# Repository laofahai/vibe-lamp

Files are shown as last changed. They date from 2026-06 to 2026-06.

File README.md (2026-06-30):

**English** | [简体中文](README.zh-CN.md)

# Vibe Lamp

Physical ambient status light for AI coding agents.

Vibe Lamp turns local coding-agent state into desk light: blue when the agent is working, green when it finishes, red when it needs you, and amber when the connection is lost.

<p align="center">
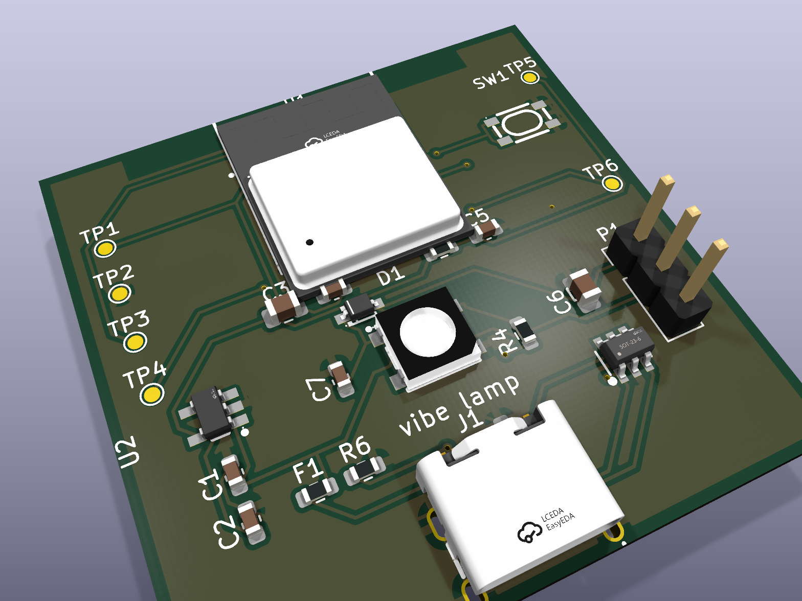
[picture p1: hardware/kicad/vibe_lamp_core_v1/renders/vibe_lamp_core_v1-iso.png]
Vibe Lamp Core V1 PCB 3D render
  
</p>

Core V1 is a complete ESP32-C3 controller board with USB-C power/programming, a board-mounted WS2812B status LED, a reset/provisioning button, and a reserved WS2812 expansion pad. The KiCad source, 3D renders, Gerber, BOM, and CPL files are included.

Inspired by [Vibe Island](https://vibeisland.app/), but independent from it. Vibe Lamp consumes agent hooks directly and can coexist with other hook consumers.

---

## Agent Support

| Level | Agents / tools | How it works |
|---|---|---|
| Built in | Claude Code, Codex | `daemon/install.py` installs local hooks and launchd autostart on macOS. |
| Generic API | OpenCode, Qwen Code, Gemini CLI, Aider, Cursor, Windsurf, CodeBuddy / WorkBuddy, Trae, MarsCode / Doubao, Factory / Droid-style tools | Any tool that can run a hook, plugin, wrapper, or notification command can POST normalized events to `/event/generic`. |
| Future adapters | Tool-specific integrations | Add adapter logic in the Mac daemon only; the ESP32 firmware stays agent-agnostic. |

Generic event example:

```bash
curl -s -o /dev/null --max-time 1 \
  -X POST http://127.0.0.1:8787/event/generic \
  -H 'Content-Type: application/json' \
  -d '{"agent":"opencode","session_id":"default","state":"working","tool":"code"}' || true
```

Supported normalized states are `idle`, `working`, `done`, `error`, and `needs_you`. See [daemon/AGENTS.md](daemon/AGENTS.md) for adapter notes.

---

## Architecture

All decision-making lives on the Mac. The ESP32 is a display endpoint.

```
Claude Code / Codex / generic agent
        │
        ▼
Mac daemon
  - normalizes hook events
  - merges multiple sessions
  - pushes state + heartbeat
        │ WiFi / HTTP
        ▼
ESP32 firmware
  - renders LED color/animation
  - enters lost state when heartbeat stops
```

Merge priority for a single LED:

```text
needs_you > error > working > done > idle
```

The lamp never freezes on stale state: if the daemon or network disappears, firmware switches to amber lost mode after the watchdog timeout.

---

## Hardware

Two hardware paths are supported:

| Path | Use it for | Notes |
|---|---|---|
| Core V1 PCBA | Finished build | Recommended. Factory-assembled ESP32-C3 board with board-mounted WS2812B. |
| Breadboard prototype | Bring-up and experiments | ESP32 dev board plus RGB LED or WS2812 ring. |

<p align="center">
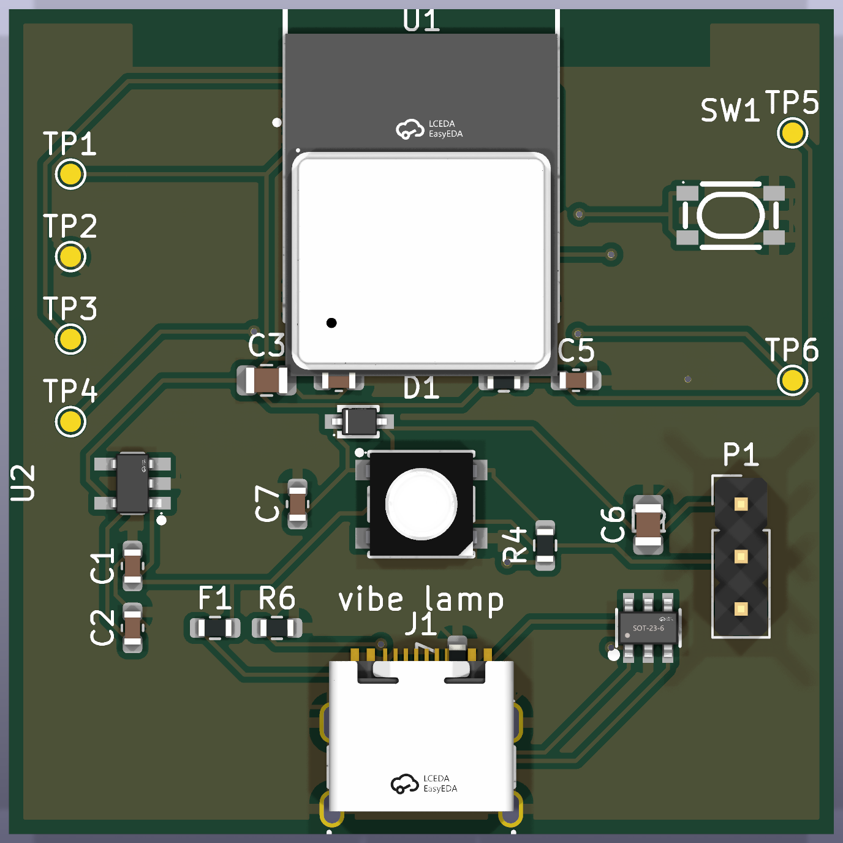
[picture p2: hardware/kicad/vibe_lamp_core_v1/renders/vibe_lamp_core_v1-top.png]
Vibe Lamp Core V1 PCB top render
  
</p>

Core V1 production files live in [hardware/kicad/vibe_lamp_core_v1](hardware/kicad/vibe_lamp_core_v1):

- KiCad PCB source
- PCB renders
- JLCPCB Gerber zip
- JLCPCB BOM and CPL

<details>
<summary>Breadboard prototype parts</summary>

RGB LED prototype:

| Part | Qty | Notes |
|---|---:|---|
| ESP32 dev board | 1 | Any `esp32dev`-compatible board |
| Common-cathode RGB LED | 1 | 4-pin LED |
| 220 ohm resistor | 3 | One per R/G/B channel |
| Breadboard | 1 | Bring-up |
| Jumper wires | Several | Board-dependent |
| USB data cable | 1 | Power and flashing |

WS2812 ring prototype:

| Part | Qty | Notes |
|---|---:|---|
| ESP32 dev board | 1 | Same firmware stack |
| WS2812 / WS2812B ring | 1 | 16 LEDs by default |
| 330 ohm resistor | 1 | In series with DIN |
| 1000 uF electrolytic capacitor | 1 | Across 5V and GND |
| Jumper wires + USB data cable | Several | Power, data, flashing |

</details>

Detailed wiring, flashing, WiFi provisioning, and self-test steps are in [HARDWARE.md](HARDWARE.md).

---

## Quick Start

```bash
# Core V1 firmware
cd firmware
pio run -e c3_core_v1 -t upload

# Mac daemon + Claude Code / Codex hooks
cd ../daemon
python install.py install
```

After WiFi provisioning, test the lamp directly:

```bash
curl --noproxy '*' -X POST http://vibelamp-<id>.local/state \
  -H 'Content-Type: application/json' \
  -d '{"sessions":[{"state":"working","tool":"code"}]}'
```

---

## Development

```bash
# Daemon tests
cd daemon
python -m pytest

# Firmware logic tests
cd ../firmware
pio test -e native

# Firmware builds
pio run -e c3_core_v1
pio run -e esp32
pio run -e esp32_ring
```

The `pio` command can use the repo virtualenv: `.venv/bin/pio`.

---

## Status

Done:

- ESP32 firmware: WiFi provisioning, HTTP state API, mDNS, watchdog lost mode, RGB/WS2812 display drivers, animations, multi-session rendering.
- macOS daemon: Claude Code and Codex hooks, generic event API, session merge, heartbeat, retry, rediscovery, launchd autostart.
- Core V1 hardware: KiCad board source, renders, JLCPCB Gerber/BOM/CPL.

Planned:

- Dedicated adapters for more coding agents.
- OTA firmware update.
- Phone control page.
- Enclosure and diffuser polish.
- BLE fallback when WiFi is unavailable.

---

## Repository Layout

```text
vibe-lamp/
├── hardware/    # Core V1 docs, KiCad source, renders, fab outputs
├── firmware/    # ESP32 firmware, PlatformIO environments, native tests
├── daemon/      # macOS daemon, hook installer, normalization logic, pytest
└── scripts/     # release packaging helpers
```

---

## License

MIT. See [LICENSE](LICENSE).

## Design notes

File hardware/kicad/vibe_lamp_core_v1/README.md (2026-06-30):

# Vibe Lamp Core V1 (KiCad)

Core V1 桌面状态灯主控板的 KiCad 工程目录。当前版本已经包含 PCB 源文件、渲染图、JLCPCB Gerber/BOM/CPL 输出，可作为 PCBA 打样下单基础。

40×40mm 圆角方板 · 2 层 · ESP32-C3-MINI-1（自带 PCB 天线，天线 keep-out 在位）· USB-C 供电+原生 USB · 板载 3.3V LDO · 板载 WS2812B 状态灯 · WS2812 扩展焊盘 · 清网按钮 · 工厂贴片，用户不焊接主板。

## 当前状态

- 电气完整：0 短路、0 未连接。
- 生产资料已生成：`fab/vibe_lamp_core_v1-gerber.zip`、`fab/vibe_lamp_core_v1-bom.csv`、`fab/vibe_lamp_core_v1-cpl.csv`。
- 3D 预览图在 `renders/`。
- 详细布线/DRC 说明见 `../../v1_routing_status.md`。

## 目录内容

| 路径 | 用途 |
|---|---|
| `vibe_lamp_core_v1.kicad_pcb` | PCB 源文件 |
| `vibe_lamp_core_v1.kicad_pro` | KiCad 工程配置 |
| `libs/` | 本工程使用的符号、封装、3D 模型 |
| `scripts/` | 生成/布线/导出辅助脚本 |
| `renders/` | 顶视与等轴测 3D 渲染图 |
| `fab/` | JLCPCB 下单文件 |

## 下单入口

1. 先读 `../../v1_routing_status.md`，确认剩余 DRC 告警的性质。
2. JLCPCB 下单时上传 `fab/vibe_lamp_core_v1-gerber.zip`。
3. 选择 PCBA 后上传 `fab/vibe_lamp_core_v1-bom.csv` 与 `fab/vibe_lamp_core_v1-cpl.csv`。
4. 被动件按阻值/容值在 JLCPCB 页面确认基础库匹配。

## 注意
- 天线 keep-out 是本板第一约束：模组天线端贴板边，该区域两层禁铜/禁走线/禁过孔/禁器件。
- 下单/编辑前留意 KiCad 自动回写 `.kicad_pro` 的问题，详见 `../../v1_routing_status.md`。

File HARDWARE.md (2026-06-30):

# Vibe Lamp · 硬件上手指南

这是一份「从硬件到灯随会话变色」的分步清单。Core V1 PCBA 是推荐路径；面包板原型保留给快速验证和固件调试。

> 命令里的 `pio` / `python` 可直接用仓库自带虚拟环境：
> - `/Users/laofahai/Documents/workspace/vibe-lamp/.venv/bin/pio`
> - `/Users/laofahai/Documents/workspace/vibe-lamp/.venv/bin/python`
>
> 下文为简洁起见写成 `pio` / `python`，把它换成上面的绝对路径即可（或先 `source .venv/bin/activate`）。

---

## 0. 你需要什么

两条路任选其一往下走：

- **Core V1 PCBA（推荐）**：使用本仓库 KiCad 工程和 `fab/` 里的 JLCPCB 文件下单，收到的是工厂贴好的主控板。用户不需要焊接主板，只需要 USB-C 烧录、配网、装外壳。
- **面包板原型**：用 ESP32 开发板、RGB LED 或 WS2812 灯环快速验证固件和灯效。

Core V1 生产资料：

| 文件 | 用途 |
|---|---|
| `hardware/kicad/vibe_lamp_core_v1/vibe_lamp_core_v1.kicad_pcb` | KiCad PCB 源文件 |
| `hardware/kicad/vibe_lamp_core_v1/renders/` | PCB 3D 渲染图 |
| `hardware/kicad/vibe_lamp_core_v1/fab/vibe_lamp_core_v1-gerber.zip` | JLCPCB Gerber 上传包 |
| `hardware/kicad/vibe_lamp_core_v1/fab/vibe_lamp_core_v1-bom.csv` | JLCPCB 贴片 BOM |
| `hardware/kicad/vibe_lamp_core_v1/fab/vibe_lamp_core_v1-cpl.csv` | JLCPCB 贴片坐标 |
| `hardware/v1_routing_status.md` | 布线、DRC、下单注意事项 |

<p align="center">
  Vibe Lamp Core V1 PCB 3D render
</p>

### 物料清单 A — 打样版（单颗共阴 RGB LED）

| 物料 | 数量 | 备注 |
|---|---|---|
| ESP32 开发板 | 1 | 手上现成的即可（`esp32dev`） |
| 共阴 RGB LED（4 脚） | 1 | 一个公共**阴极** + R/G/B 三脚 |
| 限流电阻 ~220Ω | 3 | R/G/B 各一颗 |
| 面包板 | 1 | |
| 杜邦线 | 若干 | |
| USB 数据线 | 1 | 烧录 + 供电 |

### 物料清单 B — 进阶版（WS2812 灯环）

| 物料 | 数量 | 备注 |
|---|---|---|
| ESP32 开发板 | 1 | |
| WS2812 / WS2812B 灯环（16 灯） | 1 | 可寻址，支持多会话分段 |
| 限流电阻 ~330Ω | 1 | 串在数据线 DIN 上 |
| 电解电容 ~1000µF | 1 | 并在 5V 与 GND 之间，护电源 |
| 杜邦线 | 若干 | |
| USB 数据线 | 1 | |

> 引脚以固件 `firmware/include/config.h` 的实际值为准（下面接线表已对齐）。换板/换脚改 config.h 即可，不用动业务代码。

---

## 1. 接线

### 1. Core V1 PCBA（推荐）

Core V1 的 ESP32-C3-MINI-1、USB-C、WS2812B、清网按钮、电阻电容都在工厂贴片完成。主板本身不需要用户接线。

连接关系见 `hardware/v1_wiring_diagram.svg`：

- USB-C 输入 5V，板上 LDO 输出 3.3V 给 ESP32-C3。
- 板载 D1 是 WS2812B 数字灯，`GPIO4 → R4(330Ω) → D1.DIN`。
- D1 的供电经过 D3 形成 `LED5V`，降低 WS2812B 输入高电平门槛，让 ESP32-C3 的 3.3V GPIO 稳定驱动。
- SW1 清网按钮接 `GPIO10` 到 GND，固件内部上拉。
- P1 预留外接 WS2812 灯环/灯带焊盘（5V、DATA、GND），D1 是链上第一颗。

如果只使用 Core V1 板载单灯，到这里就可以直接跳到第 2 节烧录。

### 1A. 共阴 RGB LED（打样版）

R/G/B 三脚各经一颗 ~220Ω 限流电阻接到 ESP32 对应 GPIO，公共阴极直接接 GND。

config.h 实际引脚：`PIN_RGB_R=25`、`PIN_RGB_G=26`、`PIN_RGB_B=27`。

```
  ESP32                              共阴 RGB LED
  ┌────────┐                         ┌──────────┐
  │ GPIO25 ├───[ 220Ω ]──────────────┤ R        │
  │ GPIO26 ├───[ 220Ω ]──────────────┤ G        │
  │ GPIO27 ├───[ 220Ω ]──────────────┤ B        │
  │   GND  ├─────────────────────────┤ 公共阴极  │ ← 最长那只脚
  └────────┘                         └──────────┘
```

接线要点：
- **共阴**：最长那只脚是公共**阴极**，接 GND。
- 三颗限流电阻别省，否则 LED 会过亮甚至烧。
- 如果你手上是**共阳** RGB LED（公共脚接 3.3V），公共脚改接 3.3V，并在固件驱动里把 PWM 占空比反相（`display_rgb_led.cpp` 里把每路写成 `255 - value`）。

### 1B. WS2812 灯环（进阶版）

config.h 实际数据脚：`PIN_WS2812=4`，`NUM_LEDS=16`。

```
  ESP32                        WS2812 灯环
  ┌────────┐                   ┌───────────┐
  │ GPIO4  ├──[ 330Ω ]─────────┤ DIN       │ ← 注意方向：接 DIN/IN，不是 DOUT
  │   5V   ├───────┬───────────┤ 5V / VCC  │
  │   GND  ├───┐   │           │           │
  └────────┘   │   │           └───────────┘
               │   │
               │  ═╧═  1000µF
               └───╨──┐
                  GND │
                      ▼ 并在 5V 与 GND 之间（注意电解电容极性）
```

接线要点：
- 数据线 DIN 串一颗 ~330Ω 电阻，削尖峰、护第一颗灯。
- 5V 与 GND 之间并一颗 ~1000µF 电解电容（**长脚正、短脚负，别接反**），吸收上电涌流。
- 认准灯环上的 **DIN / IN** 箭头方向，接反了不亮。
- 16 颗全亮电流不小，靠开发板 5V 供电够用；以后做长灯条要单独供电。

---

## 2. 烧录固件

插上 USB，进 firmware 目录烧录。

**Core V1 PCBA（板载 WS2812B，推荐）**：

```bash
cd firmware
pio run -e c3_core_v1 -t upload
```

**面包板打样版**（单颗 RGB LED，默认 env）：

```bash
cd firmware
pio run -e esp32 -t upload
```

**灯环版**用 `esp32_ring` env：

```bash
cd firmware
pio run -e esp32_ring -t upload
```

预期：PlatformIO 自动拉依赖（FastLED / ArduinoJson / WiFiManager），编译并烧录，最后打印 `SUCCESS`。

> 没插板也能验证工具链：把 `-t upload` 去掉只跑 `pio run -e esp32`，应编译 `SUCCESS`。

---

## 3. 配网（连 WiFi）

固件刷进去还不知道你家 WiFi 密码——**不需要手填任何文件**，开机自建热点用浏览器配。

1. 烧录后打开串口看日志：
   ```bash
   pio device monitor
   ```
   首次开机（NVS 里没凭据）串口会打印 WiFiManager 起配网门户的日志，ESP32 出现一个 WiFi 热点 **`VibeLamp-Setup-<后缀>`**（每台灯的热点名带自己 MAC 的后 6 位十六进制后缀，避免多台同名）。

2. 手机或电脑连上 `VibeLamp-Setup-<后缀>`（开放热点，无密码）。系统通常会**自动弹出配网网页**；若没弹，浏览器手动访问 `http://192.168.4.1`。配网页顶部会显示这台灯的**设备名 `vibelamp-<后缀>.local` 与 MAC**——记下它，多人同网时用来区分自己的灯。

3. 点 **Configure WiFi** → 选你家 WiFi → 填密码 → **Save**。

4. ESP32 自动重连并把凭据存进 NVS，串口回到：
   ```
   WiFi OK, http://vibelamp.local  IP=192.168.x.x
   ```
   （也能在路由器后台看到这台新设备上线。）

   > **设备名带 MAC 后缀**：mDNS 实际注册的是 `vibelamp-<后缀>.local`（如 `vibelamp-ab7834.local`），**不是**固定的 `vibelamp.local`——多人同网才不会撞名。上面串口横幅里打印的 `vibelamp.local` 不带后缀、未必能直接解析；最稳的是用串口里的 **IP**，或配网页/下文里的 `vibelamp-<后缀>.local`。

5. 在 Mac 上验证能解析到它（macOS 原生支持 `.local`）：
   ```bash
   ping vibelamp-<后缀>.local    # 把 <后缀> 换成你这台灯的实际后缀；或直接 ping 串口里的 IP
   ```
   能 ping 通即配网成功。

> **凭据持久 + 多网记忆**：拔电再上电不会再弹配网（凭据存 NVS，断电不丢）。固件把配过的网络都记进**自建多网表**（NVS 里的唯一真源），开机时扫描周围 AP、挑信号最强的已知网连接（兼容一个 SSID 多 AP 的 Mesh，多轮重试），连不上才重开配网门户。换网/搬家见下面第 8 节。

---

## 4. 手动点灯自测

不用装守护进程，直接用 `curl` 推状态，验证整条「HTTP → 渲染 → 灯」链路。逐条执行，看灯：

> **两个必带的 flag（否则常踩坑）**：
> - `-H 'Content-Type: application/json'` —— 不带的话 `curl -d` 默认按表单类型发送，固件解析不到 JSON 会返回 **400 bad json**。
> - `--noproxy '*'` —— 你的 Mac 若设了系统代理（HTTP_PROXY 等），curl 会把发往局域网灯的请求也走代理 → **502**。带上它强制直连。没设代理时它是无害的空操作，留着即可。
>
> 下面每条都已带上这两个 flag，复制即用。命令里的 `vibelamp.local` 是**占位符**——换成你这台灯的实际设备名 `vibelamp-<后缀>.local`（见第 3 节，配网页/串口里有）或它的 IP，否则解析不到。

```bash
# 干活中 → 蓝呼吸
curl --noproxy '*' -X POST http://vibelamp.local/state -H 'Content-Type: application/json' -d '{"sessions":[{"state":"working","tool":"code"}]}'

# 要你介入 → 红慢闪
curl --noproxy '*' -X POST http://vibelamp.local/state -H 'Content-Type: application/json' -d '{"sessions":[{"state":"needs_you"}]}'

# 完成 → 绿亮后渐暗
curl --noproxy '*' -X POST http://vibelamp.local/state -H 'Content-Type: application/json' -d '{"sessions":[{"state":"done"}]}'

# 出错 → 红快闪一下后弹回
curl --noproxy '*' -X POST http://vibelamp.local/state -H 'Content-Type: application/json' -d '{"sessions":[{"state":"error"}]}'

# 看设备健康状态（返回会话数、运行时长）
curl --noproxy '*' http://vibelamp.local/health
```

工具分色（`working` 状态下试不同 `tool`）：

```bash
# 写码=蓝
curl --noproxy '*' -X POST http://vibelamp.local/state -H 'Content-Type: application/json' -d '{"sessions":[{"state":"working","tool":"code"}]}'
# 跑命令=紫
curl --noproxy '*' -X POST http://vibelamp.local/state -H 'Content-Type: application/json' -d '{"sessions":[{"state":"working","tool":"command"}]}'
# 搜索=青
curl --noproxy '*' -X POST http://vibelamp.local/state -H 'Content-Type: application/json' -d '{"sessions":[{"state":"working","tool":"search"}]}'
```

**失联自测**：推一条状态后，**停 30 秒不再发**。看门狗超时后灯会转为**琥珀色慢呼吸**（失联态）。再推任意一条 `/state`，灯立即恢复正确显示。

> 灯环版还能验证多会话分段——一次推两个会话，前半圈一个状态、后半圈另一个：
> ```bash
> curl --noproxy '*' -X POST http://vibelamp.local/state -H 'Content-Type: application/json' \
>   -d '{"sessions":[{"state":"working","tool":"code"},{"state":"needs_you"}]}'
> ```
> 预期：前半圈蓝呼吸、后半圈红慢闪。

---

## 5. 接入真实会话

灯能被 `curl` 点亮后，把它接到真实的 Claude Code / Codex 会话。守护进程会把 agent 钩子事件合并成状态，自动推给灯：

```bash
cd daemon
python install.py install
```

这一步会（幂等，可重复运行，保留你已有配置）：
- 把钩子写入 Claude Code 的 `~/.claude/settings.json`（一行 `curl`，带 `--max-time 1 || true`，绝不拖慢 agent）。
- 把钩子写入 Codex 的 `~/.codex/hooks.json` 并在 `~/.codex/config.toml` 追加 notify。
- 装一个 launchd LaunchAgent（`~/Library/LaunchAgents/tech.linch.vibelamp.plist`，label `tech.linch.vibelamp`），守护进程开机自启、崩溃自动重拉。
- 生成默认配置文件（工具分色规则、会话超时等，可编辑）。

装好后，**开一个 Claude Code 或 Codex 会话跑个任务**：

- 你提交指令、它开始调用工具 → 灯**蓝呼吸**（按工具分色）。
- 它需要你批准权限 / 问你问题 → 灯**红慢闪**。
- 任务跑完 → 灯**绿亮后渐暗**回空闲。

> 想撤掉：`python install.py uninstall`（同样幂等，只移除自己加的钩子，保留你其它配置）。

---

## 6. 自定义外观

灯本身就跑着一个 HTTP 服务，浏览器打开它的设置页即可调外观（即时生效，存 NVS，断电不丢）：

```
http://vibelamp.local/
```

可调：
- **亮度**（夜里太刺眼时最常用）。
- **各状态颜色**（干活 / 完成 / 介入 / 出错 / 失联）。
- **动画快慢 / 开关**（嫌呼吸晃眼可关）。

逻辑层面的偏好（哪些工具名算 code/command/search、会话多久无活动算死、启用哪些 agent、灯地址、心跳间隔）在守护进程的配置文件里调：`~/.vibelamp/config.json`（`install.py install` 会生成默认值，编辑后重启守护进程生效）。

> 注：灯的颜色/亮度/动画属「这盏灯长什么样」，存在灯里（换电脑、重装守护进程都带着）；工具分色等属「事件怎么映射成状态」，存守护进程配置。LED 数量 / 显示类型属编译期（换硬件本就要重烧）。

---

## 7. 排障小抄

### 连不上 WiFi / 想重新配网
- 设备始终连不上、或换了路由器：让它重进配网门户，两种办法任选：
  - **开机长按按钮**：Core V1 按住板上 **SW1 清网键**（GPIO10）；部分开发板原型可按住 **BOOT 键**（GPIO0，取决于你的接线/固件配置）。断电 → 按住按钮 → 上电并保持约 **3 秒** → 串口打印「重置 WiFi 凭据」并重启 → 重新出现 `VibeLamp-Setup-<后缀>` 热点，按第 3 节重配一次。
  - **HTTP 软触发**（设备还在线时）：执行
    ```bash
    curl -X POST http://vibelamp.local/reset
    ```
    设备清掉旧凭据后重启进配网门户。（用 POST 而非浏览器直接打开，避免被恶意网页的 `<img src>` 等误触发清网。）
- 配网门户超时（约 3 分钟没人配）会自动退出继续运行，此时灯进失联态——重新触发配网即可。

### 灯不亮，查什么
- **串口先看**：`pio device monitor`，确认有没有 `WiFi OK` 和 `IP`。没连上 WiFi 自然收不到推送。
- `ping vibelamp-<后缀>.local`（或串口里的 IP）不通 → mDNS 没起来或没连网，回到第 3 节重配网。
- `curl .../state` 返回了但灯不动：
  - Core V1：确认烧的是 `c3_core_v1` env；如果误刷 `esp32` / `c3_rgb`，固件会按三路 PWM RGB LED 驱动，不会点亮板载 WS2812B。
  - RGB LED 版：确认是**共阴**且公共脚接 GND（共阳要在驱动里反相）；R/G/B 三脚和 GPIO25/26/27 没接错、限流电阻没虚接。
  - 灯环版：确认数据线接的是 **DIN**（不是 DOUT）、方向箭头对、5V/GND 没接反、电容极性没接反。
- 灯一直**琥珀慢呼吸** = 失联态，说明 30 秒内没收到 `/state`：守护进程没在推（见下）或网络断了。

### 守护进程没起来
- 查 launchd 是否加载：
  ```bash
  launchctl list | grep vibelamp
  ```
  没有这条 → 重跑 `cd daemon && python install.py install`。
- 看守护进程日志：`~/Library/Logs/` 下的 vibelamp 相关日志。
- 手动前台起一个看报错：
  ```bash
  cd daemon && python -m vibelamp
  ```
- 确认钩子真的装进去了：检查 `~/.claude/settings.json` 里有指向 `127.0.0.1:8787/event` 的 `curl` 钩子。
- 灯地址不对：守护进程绑定灯的稳定身份是 `lamp_id`（设备名）+ `lamp_mac`，IP 变了也不怕。推送失败时它会按这身份**重扫当前 /24 局域网**找回同一盏灯并自动更新 `lamp_url`（弱信号偶发整轮扫空时最多自动重扫 3 轮）。在 `~/.vibelamp/config.json` 里核对 `lamp_id` / `lamp_mac` / `lamp_url`。

---

## 8. 换网 / 搬家

**灯要换 WiFi**：不用重烧、不用拆机。按上面「重新配网」的**开机长按清网键约 3 秒**或 `curl -X POST http://vibelamp-<后缀>.local/reset`（占位符换成实际设备名或 IP），清掉旧凭据重进 `VibeLamp-Setup-<后缀>` 配网门户，配一次新 WiFi 即可。日常运行永远不用再插线。

**你的 Mac 换 WiFi**：随时切，无需任何操作。守护进程推送失败会自动按 `lamp_id`/`lamp_mac` 重扫新子网把灯找回并更新地址；弱信号偶发整轮扫空时最多自动重扫 3 轮，掉个包补一轮就抓回来。

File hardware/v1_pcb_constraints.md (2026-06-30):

# Vibe Lamp Core V1 PCB 约束

## 生产目标

- 用户不会焊接。
- 所有 V1 必需器件必须 SMT 工厂贴好。
- 不使用需要用户插针、焊线、飞线的设计。
- 板载 WS2812B 是 V1 主显示；外接 WS2812 扩展只是预留，不属于 V1 必需交付。

## PCB

- 尺寸：当前 Core V1 为 40 mm x 40 mm，圆角。
- 层数：2 层。
- 板厚：1.0 mm 或 1.2 mm。
- 阻焊颜色：建议黑色或白色，按外壳视觉选择。
- 表面处理：HASL/沉金均可；若预算允许，沉金更适合小焊盘和外观。

## 布局

正面：

- WS2812B 状态灯放中心。
- USB-C 放一边，外壳开口要预留插拔空间。
- 清网按钮放边缘，外壳可做针孔或小按键柱。

背面或非视觉区域：

- ESP32-C3-MINI-1。
- LDO、电阻、电容。
- 调试焊盘。

也可以把 ESP32-C3-MINI-1 放正面上方，但必须保证天线区域不被 LED 金属件、USB 外壳或外壳金属遮挡。

## 天线约束

- ESP32-C3-MINI-1 天线端必须靠 PCB 边缘。
- 天线下方和前方按 Espressif datasheet 做 keepout。
- keepout 区域不要铺铜、不要走线、不要放螺丝、不要靠金属外壳。
- 如果外壳有金属件，金属件必须远离天线端。

## USB

- USB-C 靠边放置。
- D+ / D- 短且并行，尽量等长。
- CC1/CC2 各接 5.1k 到 GND。
- USB 口外壳接 GND，按工程师习惯处理机壳地/板地。

## 电源

- 5V 主线从 USB-C 到 LDO、板载 WS2812B 供电路径、WS2812 预留焊盘。
- ESP32-C3 的 3V3 旁必须有 10uF + 100nF 去耦。
- LDO 输入输出电容紧贴 LDO。
- 板载 D1 使用 D3 形成 `LED5V`，保证 3.3V 数据高电平余量。
- 若未来真接 WS2812 灯环，5V/GND 走线要加宽，并安装 C6 470uF。

## 板载 WS2812B

- 放 PCB 正中心，方便扩散罩均匀出光。
- GPIO4 经 R4 330 ohm 串到 D1.DIN。
- D1.DOUT 接扩展焊盘 P1 DATA。
- D1 旁放 100nF 去耦。
- 丝印标出 D1 方向，避免贴反。

## 按钮

- SW1 放边缘，用户可通过外壳按到。
- 接 GPIO10 到 GND。
- 不使用 C3 的 BOOT/IO9 做产品清网按钮。

## 扩展焊盘

- WS2812 焊盘放背面或边缘，丝印 `5V DIN GND`。
- 如果要做到完全用户无焊接，V1 可以不对外暴露这些焊盘，只作为工程预留。

## 交付给打板/贴片方

最终应输出：

- KiCad 或立创EDA 工程文件
- Gerber
- Drill
- BOM
- CPL/坐标文件
- 装配图
- 本目录的设计说明

本文件和 `v1_schematic.md` 是画板输入，不是生产文件。

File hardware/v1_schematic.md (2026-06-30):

# Vibe Lamp Core V1 原理图连接表

这份文件是给硬件工程师画原理图用的连接说明，不是最终原理图文件。

## 电源

### USB-C 输入

- USB-C VBUS -> `+5V`
- USB-C GND -> `GND`
- CC1 -> 5.1k -> GND
- CC2 -> 5.1k -> GND
- D+ / D- -> ESP32-C3 原生 USB D+ / D-

建议：

- VBUS 后预留保险丝或 0 ohm 跳线位。
- USB 口附近预留 ESD 器件位，V1 可按成本决定是否装。

### 3.3V

- `+5V` -> LDO IN
- LDO OUT -> `+3V3`
- LDO GND -> `GND`
- LDO 输入输出按数据手册放去耦电容。

推荐 LDO：

- 优先选立创可 SMT 的 3.3V LDO，输出能力 >= 500 mA。
- 不建议用 AMS1117 做小板主 LDO，体积和热都不划算。

## ESP32-C3-MINI-1

### 必接

- 3V3 -> `+3V3`
- GND -> `GND`
- EN -> 10k 上拉到 `+3V3`
- EN -> 100 nF 到 GND（可选，提升上电复位稳定性）
- IO9/BOOT：预留测试焊盘或下载按钮位，默认上拉，不作为产品清网按钮

### USB

- USB D+ -> ESP32-C3 USB D+
- USB D- -> ESP32-C3 USB D-

USB 差分线按常规短、等长、少过孔处理。V1 低速/全速 USB，难度不高，但不要绕远。

## 板载 WS2812B 状态灯

类型：WS2812B 数字 RGB LED，作为 Core V1 主显示。

连接：

- `+5V` -> D3 1N4148WS -> `LED5V`
- `LED5V` -> D1 VDD
- D1 GND -> GND
- GPIO4 -> R4 330 ohm -> D1 DIN
- D1 DOUT -> P1 DATA 扩展焊盘
- D1 VDD/GND 就近放 C7 100 nF

说明：

- WS2812B 在 5V 供电时输入高电平门槛约为 0.7 x VDD，ESP32-C3 的 3.3V GPIO 会踩线。
- D3 把 D1 供电降到约 4.3V，使门槛降到约 3.0V，3.3V 数据高电平有余量。
- 外接灯带焊盘 P1 仍给满 5V，板载 D1 是链上第一颗。

## WS2812 预留扩展

预留 3 焊盘，丝印：

- `5V`
- `DIN`
- `GND`

连接：

- `+5V` -> WS2812_5V 焊盘（给外接灯带满 5V）
- `GND` -> WS2812_GND 焊盘
- D1 DOUT -> WS2812_DIN 焊盘

说明：

- V1 默认不装外接灯环。
- 外接灯环/灯带时，按“板载 D1 + 外接灯数”的总数配置固件 `NUM_LEDS`。
- 这个扩展口只给后续工程验证/返修使用，不要求最终用户焊接。

## 清网按钮

- GPIO10 -> 按钮一端
- 按钮另一端 -> GND
- GPIO10 使用 MCU 内部上拉
- 可额外预留 100 nF 到 GND 做简单消抖，不强制

固件：

- `-DPIN_RESET_BTN=10`

## 调试焊盘

建议预留小测试焊盘：

- 3V3
- GND
- GPIO20/U0RX
- GPIO21/U0TX
- EN
- IO9/BOOT

这些焊盘不是给用户使用，是给工程调试/救砖用。

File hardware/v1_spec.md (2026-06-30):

# Vibe Lamp Core V1 硬件规格

## 目标

V1 是一块小型桌面状态灯主控板，目标是“工厂贴好，用户不焊接”。用户拿到后只需要插 USB-C 供电，完成 WiFi 配网即可使用。

本版使用板载单颗 WS2812B 数字 RGB LED 作为主显示，预留 WS2812 灯环/灯带扩展焊盘。D1 是链上第一颗，外接扩展从 D1.DOUT 继续级联。

## 外形

- PCB：圆角方形，当前 Core V1 为 40 mm x 40 mm。
- 层数：2 层板即可。
- 厚度：1.0 mm 或 1.2 mm，便于做小外壳。
- 正面中心放 WS2812B 状态灯，外壳使用半透明扩散罩。
- USB-C 口放一边，作为供电和调试接口。
- 清网按钮放侧边或背面边缘，避免误触。

## 主控

- MCU：ESP32-C3-MINI-1 模组。
- 原因：
  - 体积比 ESP32-C3 SuperMini 载板小。
  - 自带射频匹配和天线，降低 RF 风险。
  - 支持原生 USB，后续刷机/日志更方便。
- 组装方式：SMT 工厂贴片，不要求用户焊接。

## 显示

### 主显示：板载 WS2812B

- 类型：WS2812B 数字 RGB LED。
- 立创料号：C2761795。
- DATA：GPIO4，经 R4 330 ohm 串到 D1.DIN。
- D1.DOUT 接扩展焊盘 P1 的 DATA。
- D1 就近放 C7 100 nF 去耦。
- D3 使用 1N4148WS 串在 LED 供电路径形成 `LED5V`，把 D1 供电从 USB 5V 降到约 4.3V，降低 WS2812B 输入高电平门槛，保证 ESP32-C3 的 3.3V GPIO 有足够余量。

### 预留扩展：WS2812

- 预留 3 个测试焊盘或小焊盘：
- 5V
- DATA
- GND
- DATA 来自 D1.DOUT。
- 外接灯带/灯环按总灯数重新配置固件 `NUM_LEDS`。
- V1 默认不装外接灯环，不要求用户焊接；这是给 V2 或工程验证留的扩展。

## 按钮

- 清网按钮：GPIO10 到 GND，输入上拉。
- 功能：长按清除 WiFi 凭据并重启进入配网。
- 按钮必须工厂贴好，用户不焊接。

## 供电

- 输入：USB-C 5V。
- 3.3V：板上 LDO 给 ESP32-C3-MINI-1 供电。
- 单颗 RGB 供电电流很小，普通 USB 口足够。
- WS2812 只是预留，若未来外接灯环，要按灯数重新核算 5V 电流。

## 固件目标

V1 主固件使用 `c3_core_v1` env：

- `DISPLAY_TYPE=DISPLAY_WS2812_STRIP`
- `NUM_LEDS=1`
- `PIN_WS2812=4`
- `PIN_RESET_BTN=10`

外接 WS2812 灯环/灯带时仍可复用 `c3_core_v1`，按总灯数调整 `NUM_LEDS`。

## 打样/生产要求

- 必须选择 SMT 贴片服务。
- USB-C、ESP32-C3-MINI-1、LDO、RGB LED、按钮、电阻电容都应由工厂贴好。
- 用户不做任何焊接。
- 如果找硬件工程师画板，把本目录下的 `v1_schematic.md`、`v1_bom.csv`、`v1_pcb_constraints.md` 一起给对方。

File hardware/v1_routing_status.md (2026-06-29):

# Vibe Lamp Core V1 布线状态

> 工程：`hardware/kicad/vibe_lamp_core_v1/vibe_lamp_core_v1.kicad_pcb`（KiCad 10）
> 流程：pcbnew 脚本摆件+连网 → Freerouting v1.9.0 自动布线 → 导回 SES → CC2 手补 → 双面 GND 铺铜 → JLCPCB 工艺规则 DRC。
> 板框：40×40 mm，2 层。

## 现状：✅ 电气完整、BOM 齐料、可下单 PCBA

| 指标 | 结果 |
|---|---|
| 短路 | **0** ✅ |
| 未连接 | **0** ✅ |
| DRC 违规 | **19**（全部非阻断:10 个 USB-C 连接器固有 + 9 个 cosmetic 丝印） |
| BOM 关键料号 | **7/7 已填**(U1/U2/J1/D2/D1/SW1/D3),被动件 JLCPCB 自动匹配 |

## 关键设计决策：D1 改用 WS2812B 数字灯

实查立创库后定的最优解(详见 git 历史):
- **6 脚 5050 模拟共阴 RGB 立创无现成高库存料**(模拟 5050 基本是 8 脚 RGBW 或带 IC 数字灯)。
- 改用 **WS2812B(C2761795,库存 55 万)**:单线驱动、去掉 R1/R2/R3 三个限流电阻、立创现货充足、24 位色、颜色一致。
- 数据链:`GPIO4 → R4(330Ω) → D1.DIN`;`D1.DOUT → P1`(板载 D1 是链首,P1 可级联外部灯带)。
- 新增 **C7 100nF** 给 D1 就近去耦(接 LED5V)。
- **电平保障 D3 = 1N4148WS(C2128,基础库)**:WS2812B 数据高电平门槛=0.7×VDD,5V 供电时为 3.5V > C3 的 3.3V GPIO,会"踩线"。串一颗 D3 把 D1 供电从 5V 降到 ~4.3V(新网络 `LED5V`),门槛降到 ~3.0V,3.3V 数据**稳达标**。外接灯带口 P1 仍接满 5V。**全 PCBA、无需手焊**。
- SW1 清网键改用 **SKRPABE010(C115360,库存 1.8万)**——Panasonic SMD 轻触开关现货,封装实测对得上。
- 配套固件:**新增 env `c3_core_v1`**(WS2812 单灯,GPIO4,NUM_LEDS=1)。**不影响现有 SuperMini 模拟板(env `c3_rgb`)**。

## 本轮其它改动

- **CC2 已布通**：R7 移到 J1.B5 正北空走廊,CC2 走一条 1.41mm 直线(`scripts/route_cc2.py`),0 短路。
- **J1 上移 1.2mm**:USB-C 焊盘全进板内,外壳仍 overhang 可插线。
- **品牌丝印 "vibe lamp"**:正面 + 背面大字 + 背面 "v1"。
- **设计规则 = JLCPCB 工艺**:铜到板边 0.2mm、默认间距 0.127mm、最少热焊盘臂 1。

## 剩余 18 项 DRC（全部非阻断）

| 类型 | 数量 | 性质 |
|---|---|---|
| hole_clearance / annular_width / clearance / padstack | 10 | **USB-C 连接器(立创 C165948)固有密脚/PTH**,立创自家封装,稳定可造 |
| silk_edge_clearance | 5 | U1/J1 封装丝印超出板边(贴边器件,超出部分不印)——cosmetic |
| silk_overlap / silk_over_copper | 3 | C6 位号丝印与邻件/铺铜重叠——cosmetic |

> 均为对 KiCad 通用规则的告警,**无真实设计缺陷**;JLCPCB 上传时会按自家工艺二次检查。可在 KiCad 逐条 Exclude 确认。

## WiFi 天线

ESP32-C3-MINI-1 **自带 PCB 天线 + 射频匹配,无需单独天线元件**。模组置顶、天线端朝板顶边;顶边 keep-out 规则区(y0.3–2.8mm,无铜/无走线/无过孔)在位。

## ⚠️ 注意:下单/编辑前请关闭 KiCad

KiCad 开着此工程时会**自动回写 `.kicad_pro`**,把设计规则还原成默认(铜到板边 0.5、间距 0.2),导致 DRC 假阳性变多。下单前如需重跑 DRC,请先关 KiCad,或确认 `.kicad_pro` 里 `min_copper_edge_clearance=0.2 / clearance=0.127 / min_resolved_spokes=1`。

## 打板厂要的文件（已生成在 `fab/`）

| 文件 | 用途 |
|---|---|
| `vibe_lamp_core_v1-gerber.zip` | Gerber 10 层(双面铜/阻焊/丝印 + 板框 + 钢网 + Excellon 钻孔)→ 上传 JLCPCB |
| `vibe_lamp_core_v1-bom.csv` | 物料表(JLCPCB 原生格式,6 个关键料号已填) |
| `vibe_lamp_core_v1-cpl.csv` | 贴片坐标 |

> 流程:JLCPCB 下单 → 上传 gerber.zip → 选 PCBA → 传 bom.csv + cpl.csv → 被动件(R/C/0Ω)在界面按值确认基础库即可。

## 复现命令

```bash
KPY="/Applications/KiCad/KiCad.app/Contents/Frameworks/Python.framework/Versions/Current/bin/python3"
KCLI="/Applications/KiCad/KiCad.app/Contents/MacOS/kicad-cli"
PCB=vibe_lamp_core_v1.kicad_pcb
"$KPY" scripts/gen_pcb.py                         # 摆件+连网+天线keepout+品牌丝印
"$KPY" scripts/export_dsn.py $PCB core.dsn
java -jar ~/Downloads/freerouting-1.9.0.jar -de core.dsn -do core.ses -mp 100   # 可无人值守批处理
"$KPY" scripts/import_ses.py $PCB core.ses
"$KPY" scripts/route_cc2.py $PCB                  # 手补 CC2 直线(B5→R7.1)
"$KPY" scripts/gnd_pour.py $PCB
"$KPY" scripts/set_values.py $PCB                 # 写回元件值
# .kicad_pro: min_copper_edge_clearance=0.2, Default clearance=0.127, min_resolved_spokes=1
"$KCLI" pcb drc --refill-zones --severity-all $PCB
"$KCLI" pcb export gerbers -o fab/ $PCB
"$KCLI" pcb export drill --format excellon --excellon-units mm -o fab/ $PCB
"$KCLI" pcb export pos --format csv --units mm --side both -o fab/$PCB-cpl.csv $PCB
"$KPY" scripts/gen_bom.py $PCB fab/$PCB-bom.csv
```

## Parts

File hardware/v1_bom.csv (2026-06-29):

位号 | 数量 | 器件 | 规格 | 封装 | 装配方式 | 立创料号 | 备注
U1 | 1 | 无线主控模组 | ESP32-C3-MINI-1 | 模组贴片 | 工厂贴片 | C2934569 | 乐鑫原厂;自带PCB天线无需外置天线
J1 | 1 | USB-C 母座 | USB2.0 供电+数据 | TYPE-C-31-M-12 | 工厂贴片 | C165948 | 16脚立创常用可贴片款
U2 | 1 | 3.3V 稳压 | AP2112K-3.3 (>=500mA) | SOT-25-5 | 工厂贴片 | C51118 | 主控3.3V供电
D1 | 1 | 数字RGB灯 | WS2812B (单线/24位色) | SMD5050-4P | 工厂贴片 | C2761795 | 板载灯;脚序VDD/DOUT/VSS/DIN;库存55万
D2 | 1 | USB ESD 保护 | USBLC6-2SC6 | SOT-23-6 | 工厂贴片 | C7519 | D+/D-/VBUS TVS;原型可贴可不贴
D3 | 1 | WS2812 电平保障二极管 | 1N4148WS | SOD-323 | 工厂贴片 | C2128 | 5V串压降~0.7V给D1供电(LED5V~4.3V) | 使3.3V数据达标;基础库
R4 | 1 | WS2812 数据串联电阻 | 330 欧姆 | 0603 | 工厂贴片 |  | GPIO4→R4→D1.DIN
R5 | 1 | 使能脚上拉 | 10k | 0603 | 工厂贴片 |  | EN 上拉到 3.3V
R6 | 1 | USB-C CC1 下拉 | 5.1k | 0603 | 工厂贴片 |  | CC1 到地
R7 | 1 | USB-C CC2 下拉 | 5.1k | 0603 | 工厂贴片 |  | CC2 到地
F1 | 1 | VBUS 输入保护 | 0Ω 跳线(可换PTC) | 0603 | 工厂贴片 |  | 缺省0Ω;需过流保护改自恢复保险丝
C1 | 1 | 稳压输入电容 | 1uF | 0603 | 工厂贴片 |  | LDO 输入
C2 | 1 | 稳压输出电容 | 1uF | 0603 | 工厂贴片 |  | LDO 输出
C3 | 1 | 主控储能电容 | 10uF | 0805 | 工厂贴片 |  | 靠近主控3.3V
C4 | 1 | 主控去耦 | 100nF | 0603 | 工厂贴片 |  | 靠近主控3.3V
C5 | 1 | EN 电容 | 100nF | 0603 | 工厂贴片 |  | 上电复位稳定
C7 | 1 | D1 电源去耦 | 100nF | 0603 | 工厂贴片 |  | 靠近 WS2812B 电源
SW1 | 1 | 清网按钮 | SKRPABE010 轻触开关 | SMD 4.2x3.2 | 工厂贴片 | C115360 | 接GPIO10;左侧两脚一端子
C6 | 1 | 灯带储能电容 | 470uF >=6.3V | 0805/钽 | 默认不贴(DNP) |  | 仅外接灯带时需要
P1 | 1 | 灯带扩展口 | 5V/数据/地 | 1x3 2.54排针 | 默认不贴(DNP) |  | WS2812 级联口;D1.DOUT→P1
TP1 | 1 | 测试焊盘 | 3.3V | 焊盘 | 不贴件 |  | 调试用
TP2 | 1 | 测试焊盘 | 地 | 焊盘 | 不贴件 |  | 调试用
TP3 | 1 | 测试焊盘 | UART RXD0 | 焊盘 | 不贴件 |  | 调试/串口
TP4 | 1 | 测试焊盘 | UART TXD0 | 焊盘 | 不贴件 |  | 调试/串口
TP5 | 1 | 测试焊盘 | EN | 焊盘 | 不贴件 |  | 调试用
TP6 | 1 | 测试焊盘 | IO9(下载) | 焊盘 | 不贴件 |  | 进下载模式
被动件说明 |  |  |  |  |  |  | R/C/0Ω 在 JLCPCB 下单界面按值+0603封装自动匹配基础库,无需预填料号

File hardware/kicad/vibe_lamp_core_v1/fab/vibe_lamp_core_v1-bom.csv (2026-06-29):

Comment | Designator | Footprint | LCSC Part #
0R | F1 | R_0603_1608Metric
100nF | C4,C5,C7 | C_0603_1608Metric
10k | R5 | R_0603_1608Metric
10uF | C3 | C_0805_2012Metric
1N4148WS | D3 | SOD-323_L1.8-W1.3-LS2.5-RD | C2128
1uF | C1,C2 | C_0603_1608Metric
330 | R4 | R_0603_1608Metric
5.1k | R6,R7 | R_0603_1608Metric
AP2112K-3.3 | U2 | SOT-25-5_L2.9-W1.6-P0.95-LS2.8-BL | C51118
ESP32-C3-MINI-1 | U1 | WIFIM-SMD_ESP32-C3-MINI-1 | C2934569
SW-PUSH | SW1 | KEY-SMD_4P-L4.2-W3.2-P2.20-LS4.6 | C115360
USB-C-TYPE-C-31-M-12 | J1 | USB-C_SMD-TYPE-C-31-M-12_1 | C165948
USBLC6-2SC6 | D2 | SOT-23-6_L2.9-W1.6-P0.95-LS2.8-BL | C7519
WS2812B | D1 | LED-SMD_4P-L5.0-W5.0-TL_WS2812B-B | C2761795

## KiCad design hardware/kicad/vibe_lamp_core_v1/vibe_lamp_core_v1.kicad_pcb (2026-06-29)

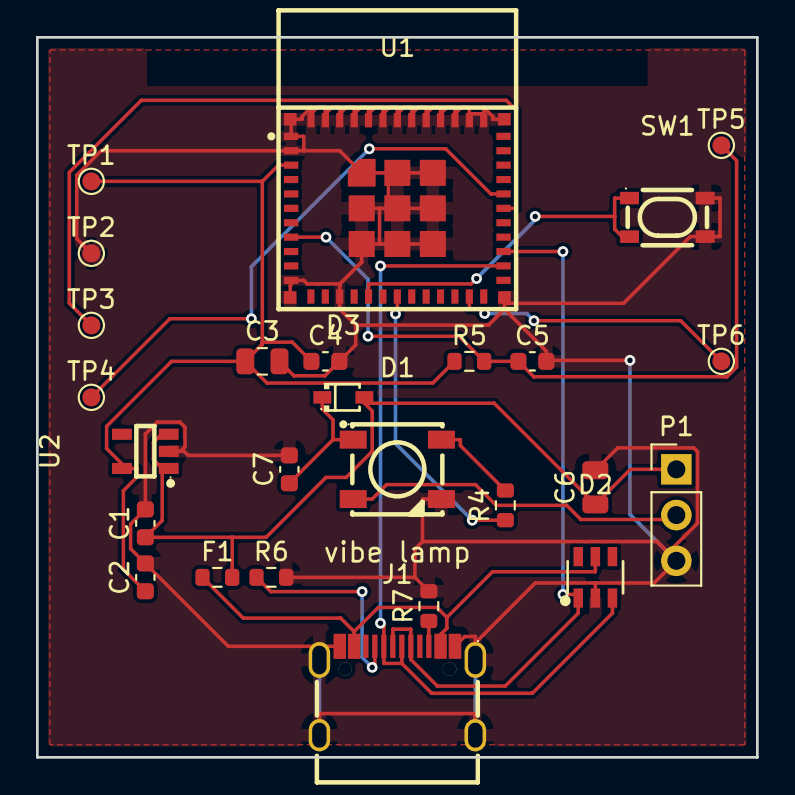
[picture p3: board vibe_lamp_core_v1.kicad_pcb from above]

Board: 2 copper layers, 40.0 x 40.0 mm, 26 parts (0 on the bottom side), 17 nets.

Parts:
C1, C2: 1uF; C_0603_1608Metric
C3: 10uF; C_0805_2012Metric
C4, C5, C7: 100nF; C_0603_1608Metric
C6: 470uF; C_0805_2012Metric
D1: WS2812B; LED-SMD_4P-L5.0-W5.0-TL_WS2812B-B
D2: USBLC6-2SC6; SOT-23-6_L2.9-W1.6-P0.95-LS2.8-BL
D3: 1N4148WS; SOD-323_L1.8-W1.3-LS2.5-RD
F1: 0R; R_0603_1608Metric
J1: USB-C-TYPE-C-31-M-12; USB-C_SMD-TYPE-C-31-M-12_1
P1: WS2812-EXT-1x3; PinHeader_1x03_P2.54mm_Vertical
R4: 330; R_0603_1608Metric
R5: 10k; R_0603_1608Metric
R6, R7: 5.1k; R_0603_1608Metric
SW1: SW-PUSH; KEY-SMD_4P-L4.2-W3.2-P2.20-LS4.6
TP1, TP2, TP3, TP4, TP5, TP6: TestPoint_Pad_D1.0mm
U1: ESP32-C3-MINI-1; WIFIM-SMD_ESP32-C3-MINI-1
U2: AP2112K-3.3; SOT-25-5_L2.9-W1.6-P0.95-LS2.8-BL

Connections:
+3V3: C2.1, C3.1, C4.1, R5.1, TP1.1, U1.3, U2.5
+5V: C1.1, C6.1, D3.2, F1.2, P1.1, U2.1, U2.3
BTN: SW1.1, SW1.3, U1.16
CC1: J1.A5, R6.1
CC2: J1.B5, R7.1
EN: C5.1, R5.2, TP5.1, U1.8
GND: C1.2, C2.2, C3.2, C4.2, C5.2, C6.2, C7.2, D1.3, D2.2, J1.1, J1.2, J1.3, J1.4, J1.A1B12, J1.B1A12, P1.3, R6.2, R7.2, SW1.2, SW1.4, TP2.1, U1.1, U1.2, U1.11, U1.14, U1.36, U1.37, U1.38, U1.39, U1.40, U1.41, U1.42, U1.43, U1.44, U1.45, U1.46, U1.47, U1.48, U1.49, U1.50, U1.51, U1.52, U1.53, U2.2
IO4: R4.1, U1.18
IO9: TP6.1, U1.23
LED5V: C7.1, D1.1, D3.1
UART_RX: TP3.1, U1.30
UART_TX: TP4.1, U1.31
USB_DM: D2.3, J1.A7, J1.B7, U1.26
USB_DP: D2.1, J1.A6, J1.B6, U1.27
VBUS: D2.5, F1.1, J1.A4B9, J1.B4A9
WS_DIN: D1.4, R4.2
WS_DOUT: D1.2, P1.2

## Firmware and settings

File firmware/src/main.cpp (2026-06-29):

#include <Arduino.h>
#include <WiFi.h>
#include "config.h"
#include "render_engine.h"
#include "display.h"
#include "net.h"
#include "api_server.h"
#include "settings_store.h"
#include "ble_state.h"

static Rgb g_pixels[NUM_LEDS];

void setup() {
  Serial.begin(115200);
  delay(300);
  display().begin();
  render_set_settings(settings_load());   // 从 NVS 恢复用户设置

  // —— 重配网入口：开机时长按按钮 → 清凭据 + 重启进配网门户 ——
  pinMode(PIN_RESET_BTN, INPUT_PULLUP);
  if (digitalRead(PIN_RESET_BTN) == LOW) {        // 上电瞬间已按下
    Serial.println("检测到重配网按钮，按住 3s 将清除 WiFi 凭据...");
    uint32_t start = millis();
    while (digitalRead(PIN_RESET_BTN) == LOW) {
      if (millis() - start >= RESET_HOLD_MS) {
        Serial.println("重置 WiFi 凭据，重启进入配网门户");
        net_reset_and_reboot();                   // 内部 resetSettings + ESP.restart()
      }
      delay(50);
    }
    // 没按满 3s 松手 → 不重置，继续正常启动
  }

  if (net_begin())
    Serial.printf("WiFi OK, http://%s.local  IP=%s\n", net_hostname(), WiFi.localIP().toString().c_str());
  else
    Serial.println("WiFi 未连接（长按 BOOT 键 3s 或访问 /reset 重新配网）");
  api_begin();

#ifdef ENABLE_BLE
  ble_state_begin();
  Serial.println("BLE 状态兜底服务已启动（设备名 VibeLamp）");
#endif
}

void loop() {
  static uint32_t boot_start = millis();
  if (millis() - boot_start < 1500) {
    Session boot{ State::BOOT, ToolKind::NONE, boot_start, 0 };
    render(&boot, 1, millis(), g_pixels, NUM_LEDS);
    display().show(g_pixels, NUM_LEDS);
    api_loop();
    delay(16);
    return;
  }
  api_loop();
  uint32_t now = millis();

  const Session* sessions = api_sessions();
  uint8_t count = api_session_count();
  uint32_t last = api_last_state_ms();

  // 看门狗：从未收到过 / 超时未收到 → 失联（仅在 WiFi 已起来后才算失联）
  bool stale = (last == 0) || (now - last > WATCHDOG_TIMEOUT_MS);

  if (stale && net_connected()) {
    Session lost{ State::LOST, ToolKind::NONE, /*since*/ (last? last+WATCHDOG_TIMEOUT_MS : 0), 0 };
    render(&lost, 1, now, g_pixels, NUM_LEDS);
  } else if (count == 0) {
    render(nullptr, 0, now, g_pixels, NUM_LEDS);   // idle
  } else {
    render(sessions, count, now, g_pixels, NUM_LEDS);
  }
  display().show(g_pixels, NUM_LEDS);
  delay(16);
}

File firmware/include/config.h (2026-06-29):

#pragma once
#include <stdint.h>

// —— 显示硬件类型（由 build_flags 的 -DDISPLAY_TYPE 选择）——
#define DISPLAY_RGB_LED     1   // 单颗共阴 RGB LED，3 路 PWM
#define DISPLAY_WS2812_RING 2   // WS2812 灯环
#define DISPLAY_WS2812_STRIP 3  // WS2812 灯条
#define DISPLAY_DISCRETE    4   // 多颗分立定色 LED

#ifndef DISPLAY_TYPE
#define DISPLAY_TYPE DISPLAY_RGB_LED
#endif

// —— 像素数（可由 build_flag -DNUM_LEDS 覆盖，例如 Core V1 板单颗 WS2812 用 1）——
#ifndef NUM_LEDS
#if DISPLAY_TYPE == DISPLAY_RGB_LED
  #define NUM_LEDS 1
#elif DISPLAY_TYPE == DISPLAY_WS2812_RING
  #define NUM_LEDS 16
#elif DISPLAY_TYPE == DISPLAY_WS2812_STRIP
  #define NUM_LEDS 8
#else
  #define NUM_LEDS 3
#endif
#endif

// —— 引脚 ——
// RGB LED（共阴；共阳需在驱动里反相）
#ifndef PIN_RGB_R
#define PIN_RGB_R 25
#endif
#ifndef PIN_RGB_G
#define PIN_RGB_G 26
#endif
#ifndef PIN_RGB_B
#define PIN_RGB_B 27
#endif
// WS2812 数据脚
#ifndef PIN_WS2812
#define PIN_WS2812 4
#endif

// —— PWM ——
#define LEDC_FREQ 5000
#define LEDC_RES  8        // 8 bit：0..255

// —— 网络 ——
#define MDNS_HOST "vibelamp"          // 设备名基准；实际 mDNS 会追加芯片 MAC 后缀，避免多人局域网冲突
#define HTTP_PORT 80
#define WATCHDOG_TIMEOUT_MS 30000UL   // 30s 无 /state → 失联

// —— 亮度上限（保护眼睛/限流）——
#define MAX_BRIGHTNESS 160

// —— 网页配网（WiFiManager）——
#define PROV_AP_NAME       "VibeLamp-Setup"   // 配网热点 SSID
#define PROV_AP_PASS       ""                 // 空 = 开放热点（家用够用；要加密改成 >=8 位）
#define PROV_PORTAL_TIMEOUT 180               // 配网门户超时（秒）；超时后退出门户继续 loop
#define WIFI_CONNECT_TIMEOUT_MS 12000UL       // 每轮自动连接已知 WiFi 的最长等待
#define WIFI_CONNECT_ROUNDS     4             // 多试几轮，避免路由器刚启动/瞬时抖动误进门户
#define WIFI_CONNECT_RETRY_DELAY_MS 1500UL    // 每轮扫描/连接失败后稍等，让射频和路由器稳定
#define PROV_CONNECT_TIMEOUT    20            // 门户提交后连接新 WiFi 的最长等待（秒），避免卡在保存页

// —— 重配网按钮（开机长按触发 resetSettings + 重开门户）——
// 用板载 BOOT 按钮（多数经典 ESP32 开发板 = GPIO0，已接上拉，按下拉低）。
// 注意 ESP32-C3：BOOT 键是 GPIO9，且是 strapping 脚——上电瞬间拉低会进「串口下载模式」、
//   固件根本不运行，所以 C3 上「开机长按 BOOT」这套用不了。C3 产品板请把按钮接到一个
//   空闲 GPIO（如 GPIO10/0/1/3/4），用 build_flag -DPIN_RESET_BTN=<gpio> 覆盖；
//   面包板没接按钮时无需理会（GPIO0 在 C3 非 strapping，INPUT_PULLUP 读高=未按，不会误触）。
//   无按钮也可随时用 HTTP `curl -X POST http://vibelamp.local/reset` 清网重配。
#ifndef PIN_RESET_BTN
#define PIN_RESET_BTN      0
#endif
#define RESET_HOLD_MS      3000UL             // 开机时长按 3s 触发重配网

// —— BLE 状态推送服务（Part B②，与配网无关，可与 WiFi 共存）——
// 仅在编译开 -DENABLE_BLE 时生效（独立 env:esp32_ble）；默认构建不含 BLE。
#define BLE_STATE_DEVICE_NAME  "VibeLamp"
#define BLE_STATE_SERVICE_UUID "6e6c0001-b5a3-f393-e0a9-e50e24dcca9e"
#define BLE_STATE_CHAR_UUID    "6e6c0002-b5a3-f393-e0a9-e50e24dcca9e"

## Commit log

2026-06-13 docs: Vibe Lamp 设计文档 + 项目骨架
    AI 编码状态实体氛围灯（Vibe Island 实体灯版）：
    agent 钩子 → Mac 转译器 → WiFi → ESP32 → WS2812 灯环
2026-06-13 docs: 设计文档自查修订
    - 钩子改走 localhost HTTP(curl)，加 --max-time/|| true 防拖垮 agent
    - ESP32 寻址用 mDNS vibelamp.local，回退固定 IP
    - 明确动画固件本地渲染、重启靠心跳自愈
    - 区分网络心跳 heartbeat 与视觉跳动脉冲 pulse
    - 打样改用单颗共阴 RGB LED（能验证完整色彩/动效）
    - 转译器语言定 Python；补 Codex session id / 无鉴权两条风险
2026-06-13 docs: 实现计划 01 ESP32 固件（含显示抽象/多会话/失联/native单测）+ 设计补显示驱动抽象
2026-06-13 docs: 实现计划 02 守护进程+Claude Code钩子+launchd（TDD/纯标准库）
2026-06-13 docs: 设计补 §13 用户自定义设置（灯设置网页+守护进程配置文件）→ 计划05
2026-06-13 docs: 实现计划 03 Codex接入 + 04 网页配网/BLE（并行起草）
    03: /event/codex 端点+claude:/codex:命名空间隔离+sidecar hooks.json幂等+Task5真机核对兜底
    04: WiFiManager@2.0.17 网页配网+重配按钮/reset+BLE配网(WiFiProv)+BLE兜底推送(bleak桥)
2026-06-13 docs: 实现计划 05 用户自定义设置（固件设置网页NVS + 守护进程config.json）
2026-06-13 feat(daemon): 包骨架 + config
2026-06-13 feat(daemon): SessionStore 合并+优先级排序+超时清理
2026-06-13 feat(daemon): Claude Code 事件归一化 + 工具分色
2026-06-13 feat(daemon): 灯客户端 push（容错不抛异常）
2026-06-13 feat(daemon): HTTP 收事件 + 心跳线程 + 入口
2026-06-13 feat(daemon): 钩子幂等合并/移除（纯函数+TDD）
2026-06-13 feat(daemon): launchd 自启 + install/uninstall CLI
2026-06-13 feat(firmware): PlatformIO 骨架 + config.h
2026-06-13 feat(firmware): 渲染引擎静态色 + native 单测
2026-06-13 feat(firmware): 渲染引擎动画（呼吸/闪/渐暗/失联）
2026-06-13 feat(firmware): 多会话分段渲染
2026-06-13 feat(firmware): 显示抽象 + RGB LED 驱动 + 动画自检
2026-06-13 feat(firmware): WiFi 连接 + mDNS vibelamp.local
2026-06-13 feat(firmware): HTTP /state /health + 看门狗失联
2026-06-13 feat(firmware): WS2812 灯环/灯条驱动（FastLED）
2026-06-13 feat(firmware): 开机扫描动画
2026-06-13 feat(daemon): Claude 端 session_id 加 claude: 命名空间前缀
2026-06-13 feat(daemon): Codex 事件归一化 + codex: 命名空间前缀 + exit_code 兜底
2026-06-13 feat(daemon): server 按端点分流 /event 与 /event/codex
2026-06-13 feat(daemon): config 增加 Codex hooks.json/config.toml 路径常量
2026-06-13 feat(daemon): Codex 配置幂等写入（hooks.json + config.toml 最小追加）
2026-06-13 feat(daemon): 读 ~/.vibelamp/config.json 覆盖默认（容错回落）
2026-06-13 feat(daemon): 工具分色表从配置读
2026-06-13 feat(daemon): install 首次生成默认 ~/.vibelamp/config.json
2026-06-13 feat(firmware): 渲染设置运行时化（颜色/动画/亮度）
2026-06-13 feat(firmware): NVS 持久化渲染设置 + 显示驱动亮度收口
2026-06-13 feat(firmware): 设置网页 + /settings 读写（NVS 持久化）
2026-06-13 feat(firmware): 引入 WiFiManager 依赖 + 配网/重置按钮常量
2026-06-13 feat(firmware): WiFiManager 网页配网替换 secrets.h 硬编码
2026-06-13 feat(firmware): 重配网入口（开机长按按钮 + /reset 端点）
    [api_server.cpp, main.cpp]
2026-06-13 fix(firmware): 更新过时的 WiFi 失败日志（不再提 secrets.h，改提重配网入口)
    [main.cpp]
2026-06-13 docs: 完整 README + 今晚硬件上手指南 HARDWARE.md
2026-06-13 feat(firmware): BLE GATT 状态兜底服务（gated ENABLE_BLE，复用 /state 路径）
    - 抽出 api_apply_state_json() 共享函数，HTTP /state 与 BLE 写特征值共用同一套
    状态写入 + 看门狗刷新（BLE 续推也刷 g_last_ms，WiFi 断时不误判失联）
    - 新增 ble_state.h/.cpp：#ifdef ENABLE_BLE 下用 core 2.0.17 自带 Bluedroid 栈开
    状态写特征值，onWrite 回调交给 api_apply_state_json()；默认构建为空实现
    - platformio.ini 加独立 [env:esp32_ble]（extends esp32 + -DENABLE_BLE +
    min_spiffs.csv 大分区）；esp32/esp32_ring 默认构建不含 BLE、产物不受影响
    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
2026-06-13 feat(daemon): BLE 兜底桥接（bleak，默认关闭，gated 增量）
    WiFi push 失败且开启时经本地 socket 投给常驻 bleak 桥接进程；默认关闭，现有 49 测试不变。bleak 列为可选依赖。
2026-06-13 docs: 澄清不依赖 Vibe Island（独立读 agent 钩子，可共存）
2026-06-13 docs: 修正 README 测试命令（须在 daemon/ 内跑）+ 更新计数 57
2026-06-13 fix(firmware): 设置页 speed_pct 钳到 1..255 防 uint8 回绕；/reset 改 POST 防 CSRF
    [api_server.cpp]
2026-06-13 fix(daemon): Codex notify 置顶为根键(TOML根键须在表前)；安装前备份用户配置(.vibelamp-bak)
2026-06-13 docs: /reset 改用 POST(防误触清网)
2026-06-13 docs: README 中英文双语(英文主 + 中文副,顶部语言切换)
    - README.md 改为英文版,作为 GitHub 首页默认展示
    - 新增 README.zh-CN.md 保留中文全文
    - 两文件顶部互加语言切换链接
    - 订正 roadmap 中过期的 pytest 数(49→57)与目录结构说明
2026-06-13 fix(daemon): config.json 真正生效 + 优雅退出 + 健壮性
    - config.json 运行期字段(灯地址/超时/心跳)改为真生效,优先级 env > config.json > 内置默认(原来这些字段写了不生效)
    - 优雅退出:SIGTERM/SIGINT → httpd.shutdown()+server_close();心跳线程改 threading.Event 可停;__main__ 兜底 KeyboardInterrupt
    - do_POST 的 Content-Length 解析加 try/except,畸形不再 500
    - handle_path_event 加 state 白名单,未知态丢弃告警
    - 新增 13 个测试(config 生效/生命周期/畸形请求),57→70 全绿
2026-06-13 fix(firmware): NVS 长度校验 + DISCRETE 编译守卫 + 防除零 + mDNS 告警
    - settings_store: 读 NVS 前校验 blob 长度==sizeof,不符回退默认,防掉电半写灌垃圾
    - display_factory: DISPLAY_DISCRETE 未实现改为清晰 #error,替代难懂的链接错
    - render_engine: tri_wave/square_wave 加 period<2 防御,解除对调用方钳制的隐式依赖
    - net: mDNS 注册失败打印中文串口告警
    - 三 env(esp32/esp32_ring/esp32_ble)全 SUCCESS,native 14 全绿
    [net.cpp]
2026-06-13 docs: 加 MIT LICENSE + README 补 esp32_ble + 订正 PostToolUseFailure
    - 新增 MIT LICENSE,README 中英文加许可证小节
    - README 目录结构补漏的 esp32_ble env(中英文)
    - 经官方文档核实 PostToolUseFailure 是 Claude 真实事件,订正 plan-03/design 中误称'虚拟名'的过期注释
2026-06-14 fix(daemon): 监听端口退回固定契约常量,消除与钩子 URL 漂移(Codex P2)
    Codex review 指出:config.json 的 listen_port 改了会让 daemon 绑定口与
    install.py 写死的钩子 curl 端口漂移,状态再也送不到灯。
    - config.LISTEN_PORT 改为固定常量(不走 config.json/环境变量)
    - install.py 的 HOOK_CMD/CODEX_HOOK_CMD 改用 config.LISTEN_PORT,二者同源不漂移
    - 测试:验证端口固定契约 + 钩子端口同源 + 保留坏 env 值忽略的防御覆盖
    - 72 测试全绿 + 端到端发送链路复验通过
2026-06-26 feat(firmware): 多 WiFi 记忆+自动择优连接+配网健壮性；附 C3 联调修复
    固件:
    - 新增 WifiCredList 纯逻辑凭据表(去重置顶/超容量淘汰最旧/长度前缀序列化),7 个 native 单测
    - net.cpp 重构:开机 WiFiMulti 自动择优连已知网(多轮抗瞬时抖动),连不上才弹门户;
    门户/autoConnect 连上后把当前网追加进表(非覆盖);/reset 清整表
    - 多网表持久化到 NVS 独立命名空间(putBytes 二进制安全,blob 含 \0)
    - 删除 WiFi.begin() 无参迁移(会误删已存凭据的坑),改用 autoConnect 兼容旧固件
    - config: 加 WIFI_CONNECT_TIMEOUT_MS/ROUNDS;PIN_RESET_BTN 可 build_flag 覆盖(C3 BOOT 坑注释)
    - c3_rgb env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
    [config.h, net.cpp, test_main.cpp]
2026-06-26 chore: gitignore .serena/（Serena MCP 工具目录，非源码）
2026-06-26 fix(daemon): 缓存 mDNS 解析 IP 加速推送 + 强制 IPv4 避开 .local 解析挂 5 秒
    部分 Mac 上解析 vibelamp.local 要 ~5s(系统先问单播 DNS 超时再落 mDNS,且 IPv6/AAAA
    查询会挂),默认 1s 推送超时必然失败、灯收不到。修复:
    - _ipify 把主机名解析成 IPv4 并按名缓存,之后直推 IP(0.1s);失败则失效缓存、重解析重试
    一次——灯换 IP(DHCP)自动跟上。名字仍是对外稳定地址,IP 仅内部加速缓存。
    - getaddrinfo 限定 AF_INET:灯是 IPv4 设备,且避开 IPv6/AAAA 解析挂数秒的坑(5.0s→0.37s)。
    - 测试用 IP lamp_url 保持无网络、快。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
2026-06-26 fix(daemon): mDNS 解析失败自动重试,容忍 .local 间歇性解析抽风
    部分网络下 ESP32 的 mDNS 广播会假死、vibelamp.local 间歇性解析不到(连 ping 都失败)。
    _resolve_ipv4 对 getaddrinfo 重试 3 次(每次间隔 0.3s)、强制 AF_INET,配合已有的 IP 缓存
    与失败重解析,缓解间歇性解析失败。注:mDNS 服务彻底假死仍需重启灯/固件层 keepalive(待办)。
2026-06-26 feat(daemon): 加调试 HTTP 面板 + ESC/kill 卡蓝自愈
    调试面板(http://127.0.0.1:8787/,纯标准库、零依赖):
    - GET / 单文件 HTML 面板,1s 轮询;当前灯色块+动画、会话表、
    事件流(最近200条)、链路健康(推灯成功/失败=灯失联)
    - GET /api/state 会话快照 + 实际上灯 wire + 链路健康 + 测试覆盖标记
    - GET /api/events 事件环形缓冲(deque 200)
    - POST /api/test 手动把灯钉在某状态色(蓝/紫/青/绿/红/灭)验证灯与链路,
    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
2026-06-26 fix(hooks): curl 加 -o /dev/null,避免 Codex 把回包当钩子 JSON 解析报错
    Codex 会把钩子命令的 stdout 当成「钩子决策 JSON」解析。我们的 curl 把 daemon 回包
    {"ok":true} 吐到 stdout → 不符合 Codex schema → 每个事件都报 "invalid ... JSON
    output"(Claude 端容忍,Codex 端严格)。Codex 官方钩子脚本无操作时本就不写 stdout,
    空 stdout 才是合法 no-op。给 curl 加 -o /dev/null 丢弃回包即可,Claude/Codex 两端通用。
    事件本身仍正常送达 daemon(已验证 codex: 会话能进 store、面板可见)。
    已安装的 ~/.codex/hooks.json 与 ~/.claude/settings.json 同步就地修好(环境文件,不入库)。
    Co-Authore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
2026-06-26 fix(daemon): ESC 卡灯自愈 v2 — working 两档超时,needs_you 持续提醒不掐断
    官方确认 ESC/Ctrl-C 中断不触发任何钩子(Stop 明确不在中断时触发),故只能靠静默超时
    兜底。改进:
    - 两档超时(按是否有工具在跑):没工具在跑(纯思考/纯文字/已被中断)用短超时
    WORKING_IDLE_TIMEOUT_SEC=90s;有长命令在跑(PreToolUse 后、PostToolUse 前)用长超时
    WORKING_TOOL_TIMEOUT_SEC=600s,避免长构建被误判空闲灭灯。
    - 只对 working 自愈:needs_you(红·该你了)/error 是「找你」态,故意不被 90s 掐断,
    一直提醒到你处理或会话 TTL 清理(用户明确要的行为——否则"该你了"会喊一半自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
2026-06-26 chore(hardware): 加入 v1 载板草图 v1_board.svg
    Codex 会话生成的 v1 载板布局草图,纳入版本控制备查(对应路线图 PCB 那步)。
2026-06-26 Release v0.2.0 OTA and device binding
    [v1_bom.csv]
2026-06-27 Fix WiFi credential source of truth
    [config.h, net.cpp]
2026-06-27 feat(daemon): add generic agent event endpoint
    [vibe_lamp_edge_v1.kicad_pcb]
2026-06-29 feat(firmware): robust multi-AP WiFi scan and connect
    Replace WiFiMulti with an explicit scan→match→connect loop: handles merged-SSID mesh (multiple BSSIDs per SSID, strongest-first), relaxes min security for WPA-only APs, resets the STA radio between attempts, and logs candidate APs + disconnect reasons. Portal submit now validates connectivity via the same multi-AP path before writing the self-managed multi-net table (single source of truth).
    [config.h, net.cpp]
2026-06-29 chore(daemon): rename launchd label to tech.linch.vibelamp
    Rename com.vibelamp.daemon → tech.linch.vibelamp across the plist template, installer, and release packager.
2026-06-29 fix(daemon): harden lamp comms for weak-signal links
    A weak-signal lamp (RSSI ~-86) responds in ~1s and occasionally drops a probe packet, which made discovery sweeps come back empty and push() time out against the old 1.0s budget, spuriously reporting the lamp offline.
    - discovery: re-sweep up to 3x when a scan finds nothing, return immediately once a lamp is seen (common case keeps its speed); probe timeout 0.35→0.5s
    - push: raise default push_timeout_sec 1.0→2.5s so the ~1s weak-signal response succeeds on the first attempt instead of falling into retry/rebind
2026-06-29 docs: sync README/HARDWARE to v0.3.0
    Update launchd label com.vibelamp.daemon → tech.linch.vibelamp; correct mDNS host to per-device vibelamp-<id>.local; document mesh-aware multi-AP connect (multi-net NVS table as single source of truth) and the daemon's auto-rediscovery by lamp_id/lamp_mac on push failure (handles lamp/Mac WiFi changes).
2026-06-29 docs(hardware): add Core V1 PCB design review and KiCad build guide
    Design review cross-checks schematic↔BOM↔spec and flags real issues (uniform 330Ω makes green/blue LED channels too dim; c3_rgb firmware lacks -DPIN_RESET_BTN=10 so the GPIO10 clear-net button is dead; USB ESD/VBUS fuse in schematic but missing from BOM; LDO/RGB-LED part selection still open). Step-by-step KiCad GUI build guide for the empty vibe_lamp_core_v1 project: concrete LCSC parts + footprints, ESP32-C3-MINI-1 antenna keep-out, 28x28 placement, routing, DRC, and JLCPCB Gerber/BOM/CPL export.
2026-06-29 fix(firmware): reset button on GPIO10 for C3 + banner uses real mDNS host
    - c3_rgb: add -DPIN_RESET_BTN=10 so the Core V1 clear-net button works. C3's BOOT (GPIO9) is a strapping pin and can't drive the boot-time reset; the default was GPIO0. Harmless on the button-less SuperMini (INPUT_PULLUP reads high = not pressed).
    - main.cpp boot banner now prints net_hostname() (vibelamp-<id>.local) instead of bare MDNS_HOST, so the printed URL actually resolves.
    [main.cpp]
2026-06-29 docs(hardware): apply Core V1 BOM fixes from design review
    - Split RGB current-limit resistors per channel (R1 470Ω red, R2/R3 150Ω green/blue) so green/blue aren't headroom-starved at 3.3V; final values pending the chosen LED's Vf.
    - Recommend AP2112K-3.3 LDO; pin U2 to SOT-23-5.
    - Add D2 (USBLC6-2SC6 ESD, DNP) and F1 (VBUS 0Ω/fuse) that the schematic referenced but the BOM lacked.
    [v1_bom.csv]
2026-06-29 feat(hardware): generate Core V1 KiCad PCB (placed + netlist)
    Real, openable KiCad 10 board for the 32x32 Core V1: ESP32-C3-MINI-1 / USB-C TYPE-C-31-M-12 / AP2112K LDO / USBLC6 ESD pulled from LCSC via easyeda2kicad, passives/LED/button/testpoints from KiCad st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
    [vibe_lamp_core_v1.kicad_pcb]
2026-06-29 wip(hardware): Core V1 auto-routed draft (Freerouting) + routing status
    Auto-routed the placed board with Freerouting v1.9.0 (~75%, 64/86 connections) + dual-layer GND pour. NOT fab-ready: 21 unrouted, 4 shorts, 17 antenna-keepout intrusions, 9 courtyard overlaps remain (see hardware/v1_routing_status.md). Reproducible pcbnew/DSN/SES scripts saved under scripts/. The clean placed+netlist base is commit 9fb418d.
    [vibe_lamp_core_v1.kicad_pcb]
2026-06-29 feat(hardware): Core V1 clean 40x40 routed board (0 shorts, 1 unrouted)
    Re-laid out on a 40x40 board with proper spacing and re-routed with Freerouting (100 passes) + dual-layer GND pour. From 86 violations/21 unconnected/4 shorts down to 23 violations/1 unconnected/0 shorts. Remaining are minor/tunable (tight clearances, GND thermals, silk, 1 unrouted net). Near fab-ready; final cleanup = relax clearance to JLCPCB spec, route 1 net, thermal tweak, then Gerber/BOM/CPL. See hardware/v1_routing_status.md.
    [vibe_lamp_core_v1.kicad_pcb]
2026-06-29 feat(hardware): Core V1 fab outputs (Gerber/drill/BOM/CPL) + component values
    Set real component values; export JLCPCB-ready Gerber+drill zip, BOM (U1/U2/J1/D2 with LCSC), and CPL placement under fab/. Board is 0 shorts, 1 unrouted net (CC2) — a draft; see v1_routing_status.md for the pre-order checklist (route CC2, fill passive LCSC, clear connector-inherent DRC).
    [vibe_lamp_core_v1-B_Courtyard.gbr, vibe_lamp_core_v1-B_Cu.gbl, vibe_lamp_core_v1-B_Fab.gbr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]
2026-06-29 feat(hardware): route CC2, fix USB-C edge fit, add "vibe lamp" silk, fab re-export
    Core V1 PCB finishing pass — board is now electrically complete:
    - CC2 routed: moved R7 (CC2 pulldown) into the clear lane due-north of
    J1.B5 so CC2 is a straight 1.41mm trace (Freerouting deprioritized it).
    scripts/route_cc2.py auto-adds it. Result: 0 shorts, 0 unconnected.
    - J1 (USB-C) shifted up 1.2mm so all pads sit on-board (shell still
    overhangs the edge for cable insertion); opened the connector fan-out
    pocket to ~3.8mm by moving the bottom passive row up.
    - Branding silkscreen "vibe lamp" on front + back, "v1" on back.
    - Design rules set to JLCPCB process (copper-to-edge 0.2mm, clearance
    0.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
    [vibe_lamp_core_v1-B_Courtyard.gbr, vibe_lamp_core_v1-B_Cu.gbl, vibe_lamp_core_v1-B_Fab.gbr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]
2026-06-29 feat(hardware,firmware): switch D1 to WS2812B, finalize Core V1 BOM
    D1 part-selection decision: 6-pin analog 5050 common-cathode RGB has no
    in-stock JLCPCB match, so switch the onboard LED to WS2812B (digital).
    Hardware (Core V1 PCB):
    - D1 -> WS2812B (LCSC C2761795, SMD5050-4P, 550k stock). Imported exact
    footprint via easyeda2kicad; pinout verified VDD/DOUT/VSS/DIN.
    - Data chain GPIO4 -> R4(330) -> D1.DIN; D1.DOUT -> P1 (onboard LED is
    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
    [v1_bom.csv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]
2026-06-29 feat(hardware): add D3 (1N4148WS) level-margin diode for WS2812B data
    WS2812B DIN high threshold = 0.7*VDD = 3.5V at 5V, above the ESP32-C3's
    3.3V GPIO (marginal). Add series diode D3 (1N4148WS, LCSC C2128, JLCPCB
    Basic, 2.4M stock) dropping D1's supply 5V -> ~4.3V (new net LED5V), so
    the threshold falls to ~3.0V and 3.3V data is solidly in spec. External
    strip header P1 stays on full +5V. Fully PCBA, no hand-soldering.
    - D3.A -> +5V, D3.K -> LED5V -> D1.VDD + C7 decap.
    - DRC: 0 short / 0 unconnected / 19 minor (10 connector-inherent + 9
    cosmetic silk). BOM now 7/7 key LCSC parts filled; gerber/cpl/bom re-exported.
    [v1_bom.csv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]
2026-06-30 docs: polish project readme and hardware docs
    [vibe_lamp_edge_v1.kicad_pcb]
2026-06-30 docs: tighten readme and agent support
